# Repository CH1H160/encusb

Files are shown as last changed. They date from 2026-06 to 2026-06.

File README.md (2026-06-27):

# encusb
A compact USB encoder interface board using the AS5600 magnetic rotary encoder.

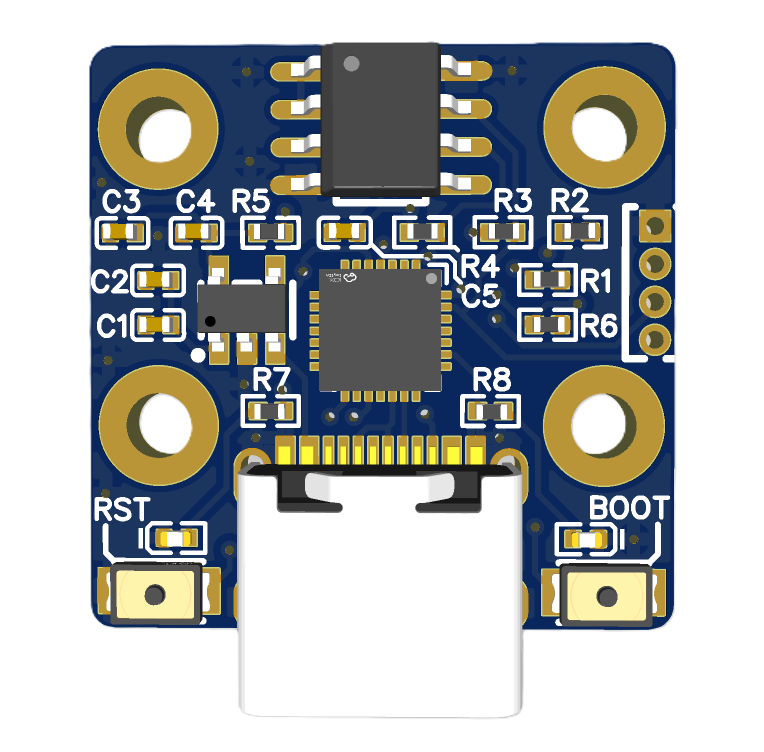
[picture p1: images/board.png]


This board reads the AS5600 angle data via I2C and outputs the encoder value through USB serial communication. It is designed for easy integration into robotics, motion control, and embedded systems.

## Features
- [AS5600(12-bit)](https://look.ams-osram.com/m/7059eac7531a86fd/original/AS5600-DS000365.pdf) magnetic encoder support
- USB serial angle output
- Error LED indicator
- Compatible with Arduino framework

## Usage
Please place the radial magnet above the AS5600 IC.
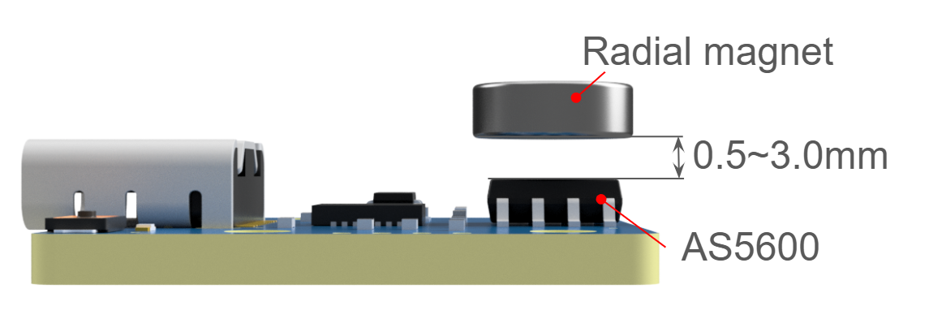
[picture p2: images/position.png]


The position changes depending on the magnet size and magnetic strength. Please fine-tune the position so that the red LED on the PCB does not light up.

The PCB can be mounted with four M2 screws.
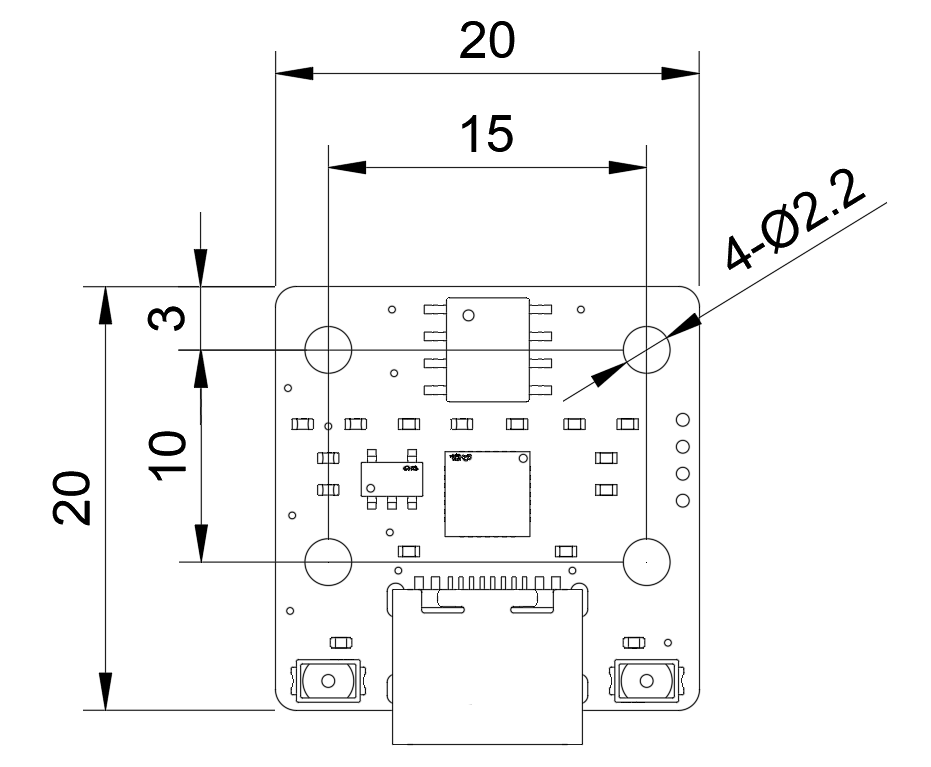
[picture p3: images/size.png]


The board outputs the raw encoder angle value through USB serial.
- Baud rate: `115200` bps
- Range: `0 - 4095`

If the magnet is not detected, `-1` is output.
If the magnet position is not correct, the LED will light up red.

## Requirement
The following environment is required for the firmware update.
- [wchisp](https://github.com/ch32-rs/wchisp)

If you want to modify the software using the Arduino framework, the following environment is required.
- [Arduino IDE](https://docs.arduino.cc/software/ide/)
- [Adafruit TinyUSB](https://github.com/Adafruit/adafruit_tinyusb_arduino)
- [arduino_core_ch32](https://learn.adafruit.com/adafruit-qt-py-ch32v203/arduino-ide-setup)
  
The modified firmware cannot be uploaded directly from the Arduino IDE.
Run `Export Compiled Binary` in the Arduino IDE, then use wchisp to upload the generated `.bin` file.

## Update
When writing the firmware, connect the USB cable first, then press the BOOT SW followed by the RST SW.
If the LED turns off, the device is ready for firmware upload.

Run `wchisp.exe flash <encusb.bin>` in the terminal.
You can specify any location for `wchisp` and the `.bin` file.

## Author
- [Ryota Kobayashi](https://x.com/CH1H160/)

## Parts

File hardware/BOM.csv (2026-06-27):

ID | Name | Designator | Footprint | Quantity | Manufacturer Part | Manufacturer | Supplier | Supplier Part | Price
1 | Mounting-Hole-2.2mm | MH5,MH6,MH7,MH8 | MOUNTING-HOLE-2.2MM-WITHOUT-DST | 4
2 | 10kΩ | R7,R5,R6 | R0402 | 3 | 0402WGF1002TCE | UNI-ROYAL(厚声) | LCSC | C25744 | 0.003
3 | 1kΩ | R8 | R0402 | 1 | 0402WGF1001TCE | UNI-ROYAL(厚声) | LCSC | C11702 | 0.004
4 | GL0402UR01 | LED2 | LED0402-RD | 1 | GL0402UR01 | Guiguang light(桂光光电) | LCSC | C51933301 | 0.007
5 | GL0402UG01 | LED1 | LED0402-RD | 1 | GL0402UG01 | Guiguang light(桂光光电) | LCSC | C51933302 | 0.01
6 | 1uF | C2,C4 | C0402 | 2 | CL05A105KA5NQNC | SAMSUNG(三星) | LCSC | C52923 | 0.016
7 | 10uF | C3,C1 | C0402 | 2 | CL05A106MQ5NUNC | SAMSUNG(三星) | LCSC | C15525 | 0.03
8 | 4.7kΩ | R3,R4 | R0402 | 2 | 0402WGF4701TCE | UNI-ROYAL(厚声) | LCSC | C25900 | 0.001
9 | 5.1kΩ | R1,R2 | R0402 | 2 | RC0402JR-075K1L | YAGEO(国巨) | LCSC | C105873 | 0.001
10 | CH32V203G6U6 | IC1 | QFN-28_L4.0-W4.0-P0.40-BL-EP2.7 | 1 | CH32V203G6U6 | WCH(南京沁恒) | LCSC | C5142280 | 0.705
11 | HX TS2306A 160GF | SW1,SW2 | SW-SMD_L3.0-W2.0-LS3.5 | 2 | HX TS2306A 160gf | hanxia(韩下) | LCSC | C25168823 | 0.048
12 | AP2112K-3.3TRG1(MS) | IC2 | SOT-23-5_L2.9-W1.6-P0.95-LS2.7-BR | 1 | AP2112K-3.3TRG1(MS) | MSKSEMI(美森科) | LCSC | C22365427 | 0.078
13 | AS5600-ASOT | IC3 | SOIC-8_L5.0-W4.0-P1.27-LS6.0-BL | 1 | AS5600-ASOT | ams(艾迈斯半导体) | LCSC | C499458 | 1.052
14 | USB-TYPE-C-018 | USB1 | USB-C_SMD-TYPE-C-31-M-12 | 1 | USB-TYPE-C-018 | DEALON(德艺隆) | LCSC | C2927038 | 0.057
15 | 100nF | C5 | C0402 | 1 | CL05A104KA5NNNC | SAMSUNG(三星) | LCSC | C100072 | 0.003

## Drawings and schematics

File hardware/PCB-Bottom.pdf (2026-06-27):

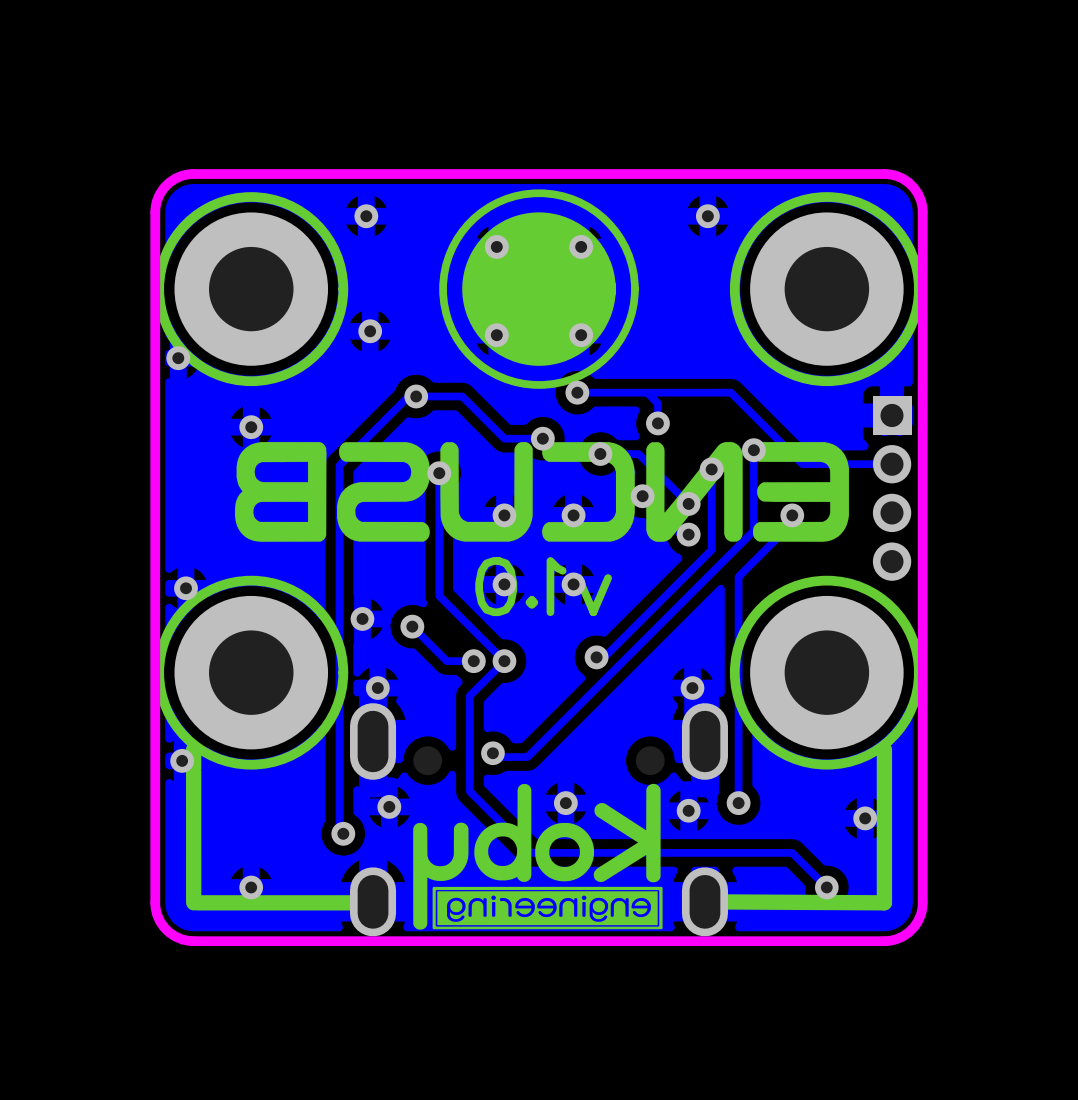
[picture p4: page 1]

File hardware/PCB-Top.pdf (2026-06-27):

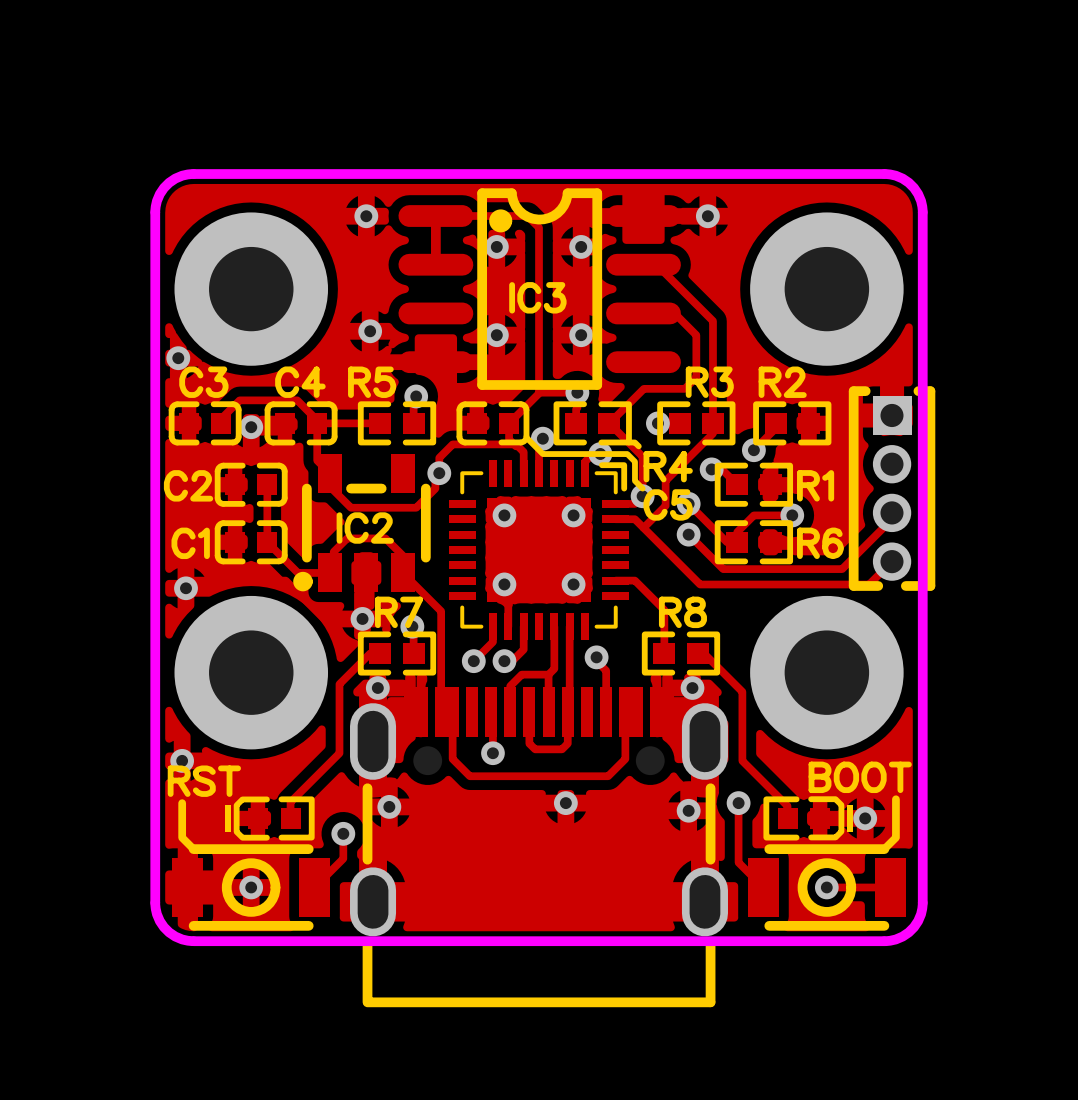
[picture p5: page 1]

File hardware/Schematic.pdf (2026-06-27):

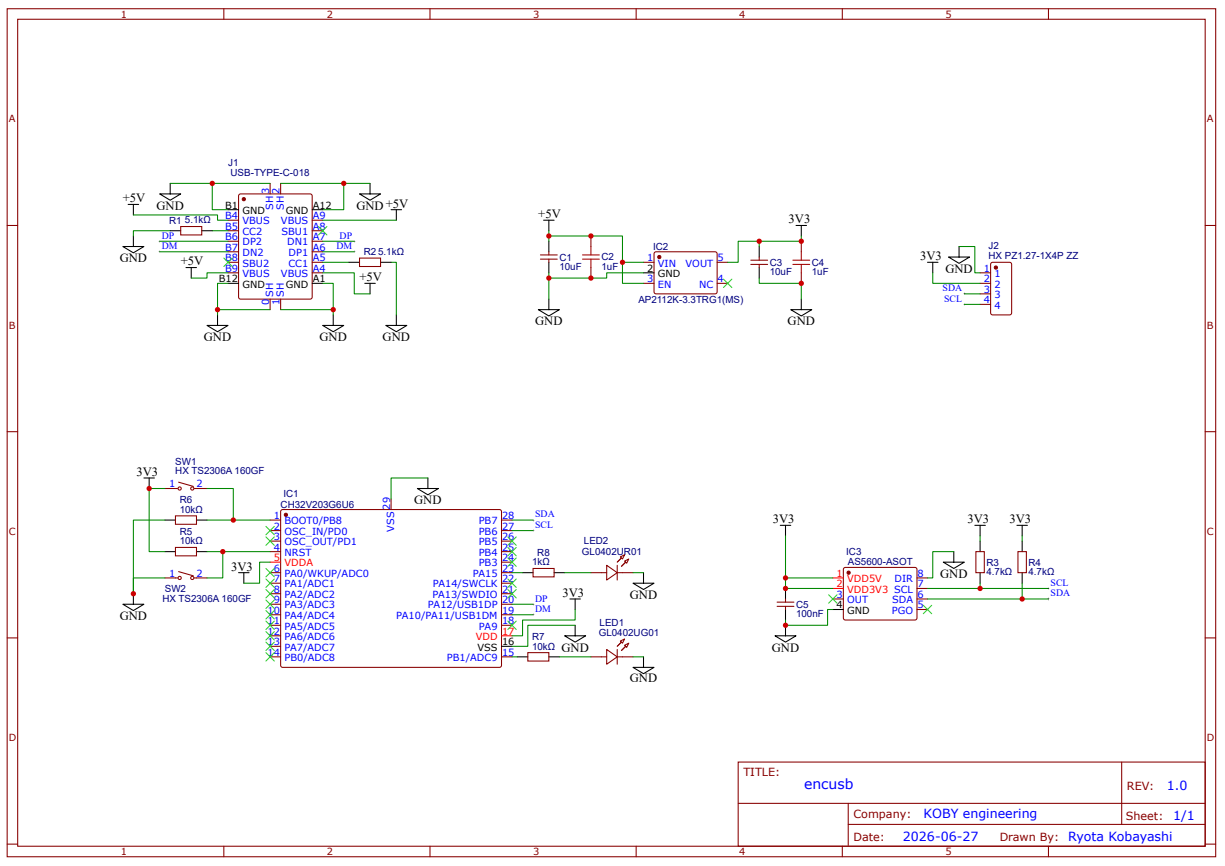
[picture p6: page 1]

Drawn By: Ryota Kobayashi

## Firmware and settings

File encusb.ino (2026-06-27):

#include <Wire.h>
#include "Adafruit_TinyUSB.h"

/**
 * @file encusb.ino
 * @brief Outputs AS5600 angle values through USB serial communication
 */

/**
 * @brief LED pin definitions
 */
constexpr uint8_t LED_ERROR = PA15;
constexpr uint8_t LED_POWER = PB1;

/**
 * @brief AS5600 I2C address
 */
constexpr uint8_t AS5600_ADDR = 0x36;

/**
 * @brief AS5600 register addresses
 */
constexpr uint8_t REG_STATUS = 0x0B;
constexpr uint8_t REG_RAW_ANGLE = 0x0C;

/**
 * @brief AS5600 status bits
 */
constexpr uint8_t STATUS_MD = 0x20;  ///< Magnet detected
constexpr uint8_t STATUS_ML = 0x10;  ///< Magnet strength too low
constexpr uint8_t STATUS_MH = 0x08;  ///< Magnet strength too high

/**
 * @brief Reads data from an AS5600 register
 *
 * @param reg Register address to read
 * @param data Buffer to store received data
 * @param len Number of bytes to read
 *
 * @return true Read successful
 * @return false Communication failed
 */
bool readRegister(uint8_t reg, uint8_t* data, uint8_t len)
{
  Wire.beginTransmission(AS5600_ADDR);

  Wire.write(reg);

  if (Wire.endTransmission(false) != 0)
    return false;

  if (Wire.requestFrom(AS5600_ADDR, len) != len)
    return false;

  for (uint8_t i = 0; i < len; i++)
  {
    data[i] = Wire.read();
  }

  return true;
}


/**
 * @brief Reads the raw angle value from AS5600
 *
 * @return 12-bit angle value (0-4095)
 */
uint16_t readAngleRaw()
{
  uint8_t data[2];

  if (!readRegister(REG_RAW_ANGLE, data, 2))
    return 0;

  return (((uint16_t)data[0] << 8) | data[1]) & 0x0FFF;
}


/**
 * @brief Reads the AS5600 status register
 *
 * @return Status bit field
 */
uint8_t readStatus()
{
  uint8_t status = 0;

  readRegister(
    REG_STATUS,
    &status,
    1
  );

  return status;
}


/**
 * @brief Controls the error LED
 *
 * @param error true to turn on the LED
 */
void setErrorLED(bool error)
{
  digitalWrite(
    LED_ERROR,
    error ? HIGH : LOW
  );
}


/**
 * @brief Initialization routine
 */
void setup()
{
  if (!TinyUSBDevice.isInitialized())
  {
    TinyUSBDevice.begin(0);
  }

  SerialTinyUSB.begin(115200);
  Wire.begin();

  pinMode(LED_POWER, OUTPUT);
  pinMode(LED_ERROR, OUTPUT);

  digitalWrite(LED_POWER, HIGH);
  digitalWrite(LED_ERROR, LOW);
}


/**
 * @brief Main loop
 */
void loop()
{
#ifdef TINYUSB_NEED_POLLING_TASK
  TinyUSBDevice.task();
#endif

  uint8_t status = readStatus();
  bool error = true;
  int16_t angle = -1;

  if (status & STATUS_MD)
  {
    angle = readAngleRaw();
    if (!(status & (STATUS_ML | STATUS_MH)))
    {
      error = false;
    }
  }

  setErrorLED(error);
  SerialTinyUSB.println(angle);

  delay(1);
}
